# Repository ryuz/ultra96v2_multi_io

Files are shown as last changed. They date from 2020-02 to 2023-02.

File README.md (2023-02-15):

# Ultra96V2用マルチI/O拡張カード

現在デバッグ中ですが、MIPI-CSI の動作確認できました。

## 開発イメージ

下記のようなイメージで開発している [Ultra96V2](https://www.avnet.com/wps/portal/japan/products/product-highlights/ultra96/) 向けのI/O拡張ボードです。

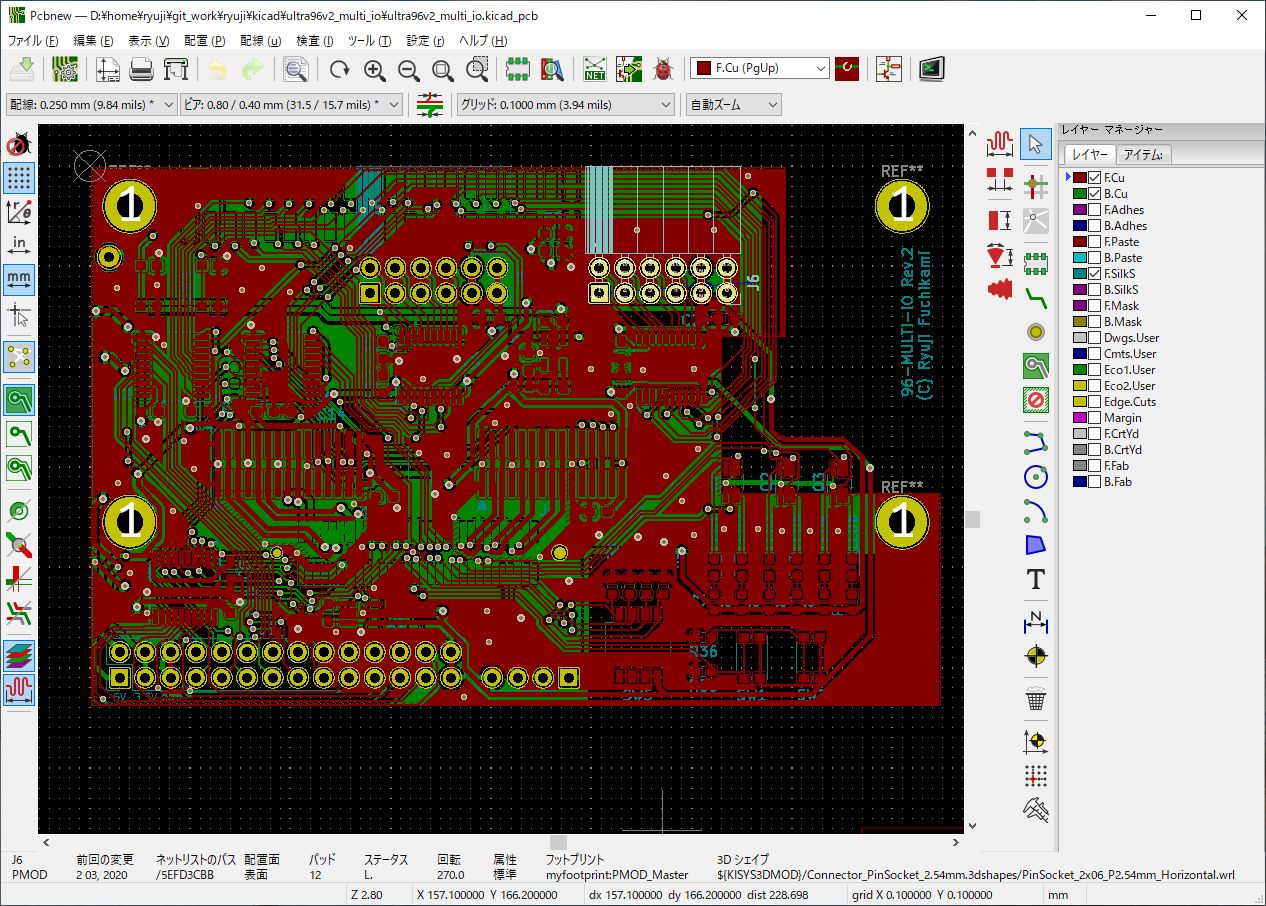
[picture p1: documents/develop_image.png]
開発イメージ
 

## 設計コンセプト

コンセプトは

- [FusionPCB](https://www.fusionpcb.jp)さんの$4.9基板で作る
- [ZYBO](https://reference.digilentinc.com/reference/programmable-logic/zybo-z7/start) の良さ(PLのI/O機能の充実)の追加
- [Raspberry PI](https://ja.wikipedia.org/wiki/Raspberry_Pi) の良さ(PSのI/O機能の充実)の追加
- 使いたい機能だけ部品実装すれば最低限のコストで使える

です。

## 機能

主な機能として

- PLの機能
    - TXS0108で3.3V双方向変換した12pin PMOD × 2個
    - RaspberryPI互換 MIPI-CSIコネクタ× 2個
    - LED × 4個
    - プッシュスイッチ × 2個 
    - ディップスイッチ(4bit) × 1個 
    - 25MHzクロック供給
- PSの機能
    - LED × 2個
    - TXS0108で3.3V双方向変換したGPIO
    - TXS0108で3.3V双方向変換したI2C
    - TXS0108で3.3V双方向変換したSPI
- その他の機能
    - 隠れると困るPWR/RSTスイッチの引き出し
    - 申し訳程度にUSB2.0信号を引き出したピンヘッダ

特に MIPI-CSI は、[こちら](http://nahitafu.cocolog-nifty.com/nahitafu/2008/11/post-57a1.html)を参考にさせて頂いて、基板厚 0.6mm の想定で設計時の机上計算のみ行っています)。

## 回路図

回路図は[こちら](documents/ultra96v2_multi_io_schematic.pdf)

## 追加情報

こちらに[ブログ記事](https://ryuz.hatenablog.com/entry/2020/07/26/215500)を書きました。

## 修正履歴

- Rev.1 2020/02/11
   - 修正内容
       - 初版
   - 動作状況
       - MIPI-CSI が同パターンの別基板でデータ受信でき無かったため、部品温存で試さずに Rev.2 製造へ

- Rev.2 2020/03/08
   - 修正内容
       - MIPI 配線レイアウト変更
       - 基板厚を 0.6mm に変更して発注
   - 動作状況
       - J3のMIPI-CSI動作確認(I2Cプルアップをリワーク修正)
       - J4のMIPI-CSI動作確認(I2Cプルアップをリワーク修正)
       - PMODの出力パルス波形確認
       - SW5(DIP-SW)の型番とフットプリントが不一致で実装できず
       - MIPI-DSIの端子をLVCMOS利用箇所でLVCMOS18と勘違いしておりLED点灯が暗い(実際はLVCMOS12)
       - 他はこれから試す予定

- Rev.3 2023/02/15
   - MIPI-CSI用 I2C プルアップ抵抗抜け修正(R23～26追加)
   - LS_GPIO_2 と LS_GPIO_6 の U4 への接続をスワップ
   - Q1-4 の DMN63D8LDW-7 -> DMN5L0-6DWK7 に変更(LVCMOS12対応)
   - SW5 の GDH04S04 のフットプリントが A6H-4101 用になっていたので両対応パターンに変更
   - fumi氏に HSコネクタに来ている信号のうち Bank65 に繋がるものがは 1.2V だと指摘頂き下記を修正
       - SW1, SW2, SW5 を FPGA内部PULLUPして論理逆で使う方針に変更(R35, R36, R31, R32, R33, R34 削除)
       - U3 を使わずにそのままピンヘッダへ (U3, C8, C10, R11, R12 削除)
       - KiCAD を 7.0.0 へ更新

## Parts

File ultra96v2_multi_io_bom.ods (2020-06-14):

Reference | Quantity | Value |  |  |  | digikey |  | Footprint | Datasheet
C1 C2 C6 | 3 | 10uF | 22 | 66 | GRM188R60J106KE47D | 490-12538-1-ND | https://www.digikey.jp/product-detail/ja/murata-electronics/GRM188R60J106KE47D/490-12538-1-ND/5797528 | Capacitor_SMD:C_0603_1608Metric_Pad1.05x0.95mm_HandSolder | ~
C12 C11 C13 C15 C18 C19 C14 C16 C7 C4 C5 C8 C10 | 13 | 0.1uF | 12 | 156 | C0603C104Z3VACTU | 399-1100-1-ND | https://www.digikey.jp/product-detail/ja/kemet/C0603C104Z3VACTU/399-1100-1-ND/411375 | Capacitor_SMD:C_0603_1608Metric_Pad1.05x0.95mm_HandSolder | ~
C3 C17 C20 | 3 | 4.7uF | 20 | 60 | CC0603ZRY5V5BB475 | 311-1453-1-ND | https://www.digikey.jp/product-detail/ja/yageo/CC0603ZRY5V5BB475/311-1453-1-ND/2833759 | Capacitor_SMD:C_0603_1608Metric_Pad1.05x0.95mm_HandSolder | ~
C9 | 1 | <0.1uF> |  | 0 |  |  |  | Capacitor_SMD:C_0603_1608Metric_Pad1.05x0.95mm_HandSolder | ~
J1 | 1 | TE 5179030-2 | 690 | 690 | 61083-063402LF | 609-1679-1-ND | https://www.digikey.jp/product-detail/ja/amphenol-icc-fci/61083-063402LF/609-1679-1-ND/1002898 | myfootprint:61083-063402LF | ~
J2 | 1 | 57202-G52-20LF | 576 | 576 | 57202-G52-20LF | 609-2632-ND | https://www.digikey.jp/products/ja?keywords=57202-G52-20LF | myfootprint:PinHeader_2x20_P2.00mm_Vertical_SMD_REV | ~
J4 J3 | 2 | 1-1734248-5 | 123 | 246 | 1-1734248-5 | A101418CT-ND | https://www.digikey.jp/product-detail/ja/te-connectivity-amp-connectors/1-1734248-5/A101418CT-ND/2567554 | myfootprint:55510-140LF | ~
J5 J6 | 2 | PMOD | 138 | 276 | SSW-106-02-T-D-RA | SAM10026-ND | https://www.digikey.jp/product-detail/ja/samtec-inc/SSW-106-02-T-D-RA/SAM10026-ND/6678763 | myfootprint:PMOD_Master | ~
J7 | 1 | PinHeader |  | 0 |  |  |  | Connector_PinHeader_2.54mm:PinHeader_2x14_P2.54mm_Vertical | ~
J8 | 1 | Conn_01x04 |  | 0 |  |  |  | Connector_PinHeader_2.54mm:PinHeader_1x04_P2.54mm_Vertical | ~
L2 | 1 | 2.2uH 2012 | 34 | 34 | LQM21PN2R2MC0D | 490-4994-1-ND | https://www.digikey.jp/product-detail/ja/murata-electronics/LQM21PN2R2MC0D/490-4994-1-ND/1788292 | Inductor_SMD:L_0805_2012Metric | ~
LED1 LED2 LED3 LED4 LED5 LED6 | 6 | SML-512MWT86 | 53 | 318 | SML-512MWT86 | 511-1313-1-ND | https://www.digikey.jp/product-detail/ja/rohm-semiconductor/SML-512MWT86/511-1313-1-ND/637126 | LED_SMD:LED_0603_1608Metric_Pad1.05x0.95mm_HandSolder | https://www.prtice.info/IMG/pdf/CQY99.pdf
Q1 Q2 Q3 | 3 | DMN63D8LDW-7 | 36 | 108 |  | DMN63D8LDW-7CT-ND | https://www.digikey.jp/product-detail/ja/diodes-incorporated/DMN63D8LDW-7/DMN63D8LDW-7CT-ND/3829373 | Package_TO_SOT_SMD:SOT-363_SC-70-6_Handsoldering | http://www.irf.com/product-info/datasheets/data/irf7309ipbf.pdf
R15 R16 R17 R18 R14 R20 R7 R8 R2 R12 | 10 | <0> |  | 0 |  |  |  | Resistor_SMD:R_0603_1608Metric | ~
R3 R4 R5 R6 R9 R10 | 6 | 200 | 12 | 72 | RC0603FR-07200RL | 311-200HRCT-ND | https://www.digikey.jp/product-detail/ja/yageo/RC0603FR-07200RL/311-200HRCT-ND/729990 | Resistor_SMD:R_0603_1608Metric | ~
R30 R13 R19 R1 R11 R21 R22 | 7 | 0 | 12 | 84 | RC0603JR-070RL | 311-0.0GRCT-ND | https://www.digikey.jp/product-detail/ja/yageo/RC0603JR-070RL/311-0.0GRCT-ND/729622 | Resistor_SMD:R_0603_1608Metric | ~
R36 R35 R34 R33 R32 R31 | 6 | 4.7k | 12 | 72 | RC0603JR-074K7L | 311-4.7KGRCT-ND | https://www.digikey.jp/product-detail/ja/yageo/RC0603JR-074K7L/311-4.7KGRCT-ND/729732 | Resistor_SMD:R_0603_1608Metric | ~
SW1 SW2 SW3 SW4 | 4 | KMR213G LFG | 77 | 308 | KMR223GLFG | 401-1428-1-ND | https://www.digikey.jp/product-detail/ja/c-k/KMR223GLFG/401-1428-1-ND/550463 | Button_Switch_SMD:SW_Push_1P1T_NO_CK_KMR2 | ~
SW5 | 1 | GDH04S04 | 210 | 210 | GDH04S04 | 450-1353-ND | https://www.digikey.jp/products/ja?keywords=GDH04S04 | Button_Switch_SMD:SW_DIP_SPSTx04_Slide_Omron_A6H-4101_W6.15mm_P1.27mm | ~
TP1 | 1 | TP_GND |  | 0 |  |  |  | TestPoint:TestPoint_Loop_D1.80mm_Drill1.0mm_Beaded | ~
U1 | 1 | LM3671MF-3.3 | 166 | 166 |  | LM3671MF-3.3/NOPBCT-ND | https://www.digikey.jp/product-detail/ja/texas-instruments/LM3671MF-3.3-NOPB/LM3671MF-3.3-NOPBCT-ND/1590190 | Package_TO_SOT_SMD:TSOT-23-5 | http://www.ti.com/lit/ds/symlink/lm3670.pdf
U4 U6 U5 U2 U3 | 5 | TXS0108EPW | 193 | 965 |  | 296-23011-1-ND | https://www.digikey.jp/product-detail/ja/texas-instruments/TXS0108EPWR/296-23011-1-ND/1775304 | Package_SO:TSSOP-20_4.4x6.5mm_P0.65mm | www.ti.com/lit/ds/symlink/txs0108e.pdf
X1 | 1 | SIT2024BA-S3-18E-25.000000G | 251 | 251 |  | 1473-SIT2018AE-S3-18N-20.000000E-ND | https://www.digikey.jp/product-detail/ja/sitime/SIT2024BA-S3-18E-25.000000G/1473-1594-1-ND/6677389 | Package_TO_SOT_SMD:SOT-23-5_HandSoldering
X2 | 1 | <xxxMHz> |  | 0 |  |  |  | Oscillator:Oscillator_SMD_Abracon_ASDMB-4Pin_2.5x2.0mm | https://abracon.com/Oscillators/ASDMB.pdf
 |  |  |  | 4658

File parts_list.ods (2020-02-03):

 |  |  |  | 個数 |  | RS-ONLINE | digikey | 備考
LSコネクタ |  | 57202-G52-10LF |  | 5 | 288 | https://jp.rs-online.com/web/p/pcb-headers/6737604/ | https://www.digikey.jp/product-detail/ja/amphenol-icc-fci/57202-G52-20LF/609-2632-ND/1090245 | 57202-G52-20LFが手に入る場合は1個
HSコネクタ | TE | TE 5179030-2 |  | 1 | 498 | https://jp.rs-online.com/web/p/pcb-headers/3616620/ |  | 61083-063402LF でもよい
保護ダイオード？
双方向レベル変換 |  | TXB0108PWR |  | 2 | 168 | https://jp.rs-online.com/web/p/voltage-translators/7099038/ | https://www.digikey.jp/product-detail/ja/texas-instruments/TXB0108PWR/296-21527-1-ND/1305700
抵抗内蔵トランジスタ | Rhom | DTC114EKAT146 | TO-236-3、SC-59、SOT-23-3 | 8 |  | https://jp.rs-online.com/web/p/digital-transistors/2461693/ | https://www.digikey.jp/product-detail/ja/rohm-semiconductor/DTC114EKAT146/DTC114EKAT146CT-ND/650710
LED |  | SML-512MWT86 |  | 8 |  | https://jp.rs-online.com/web/p/leds/7007972/
 |  | SSM3K15F
 | OSC | SIT2024BA-S3-18E-25.000000G

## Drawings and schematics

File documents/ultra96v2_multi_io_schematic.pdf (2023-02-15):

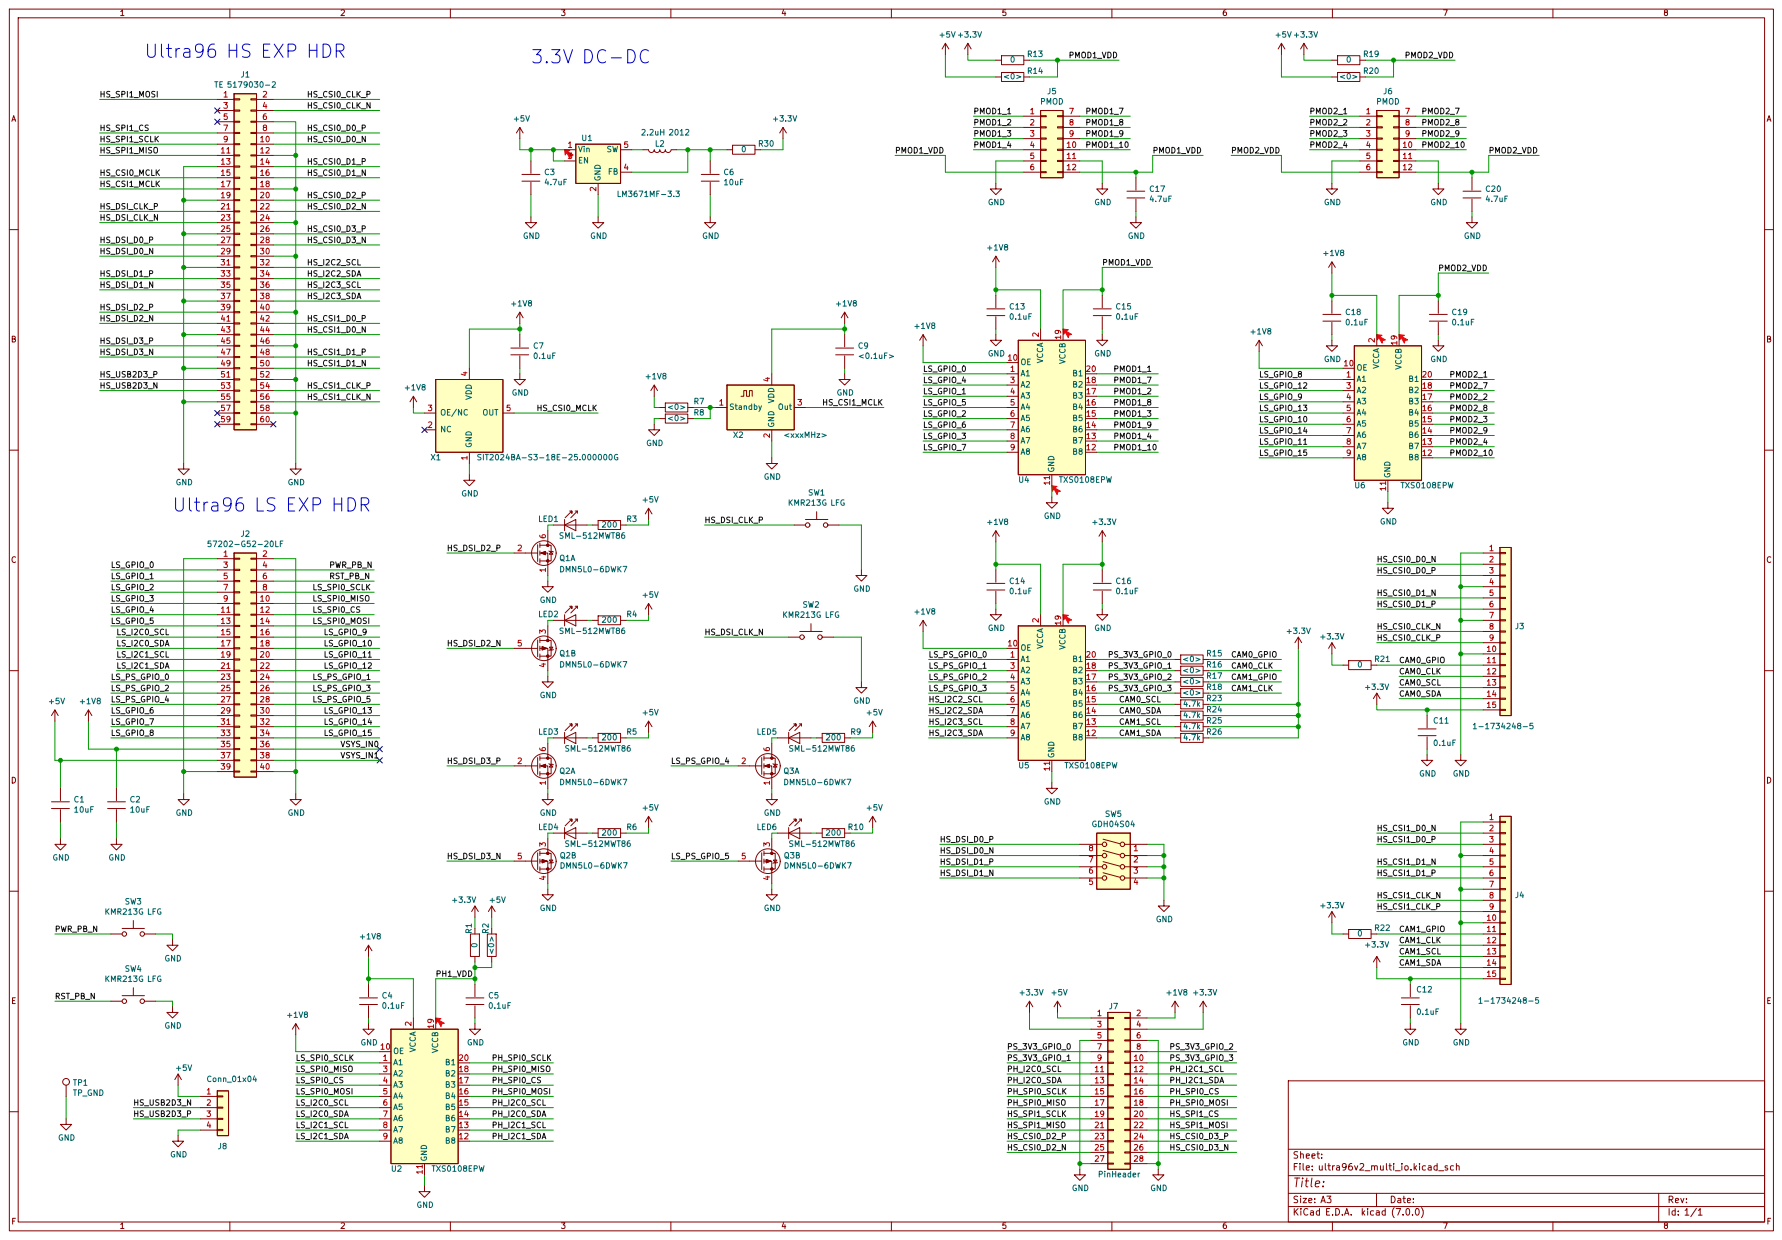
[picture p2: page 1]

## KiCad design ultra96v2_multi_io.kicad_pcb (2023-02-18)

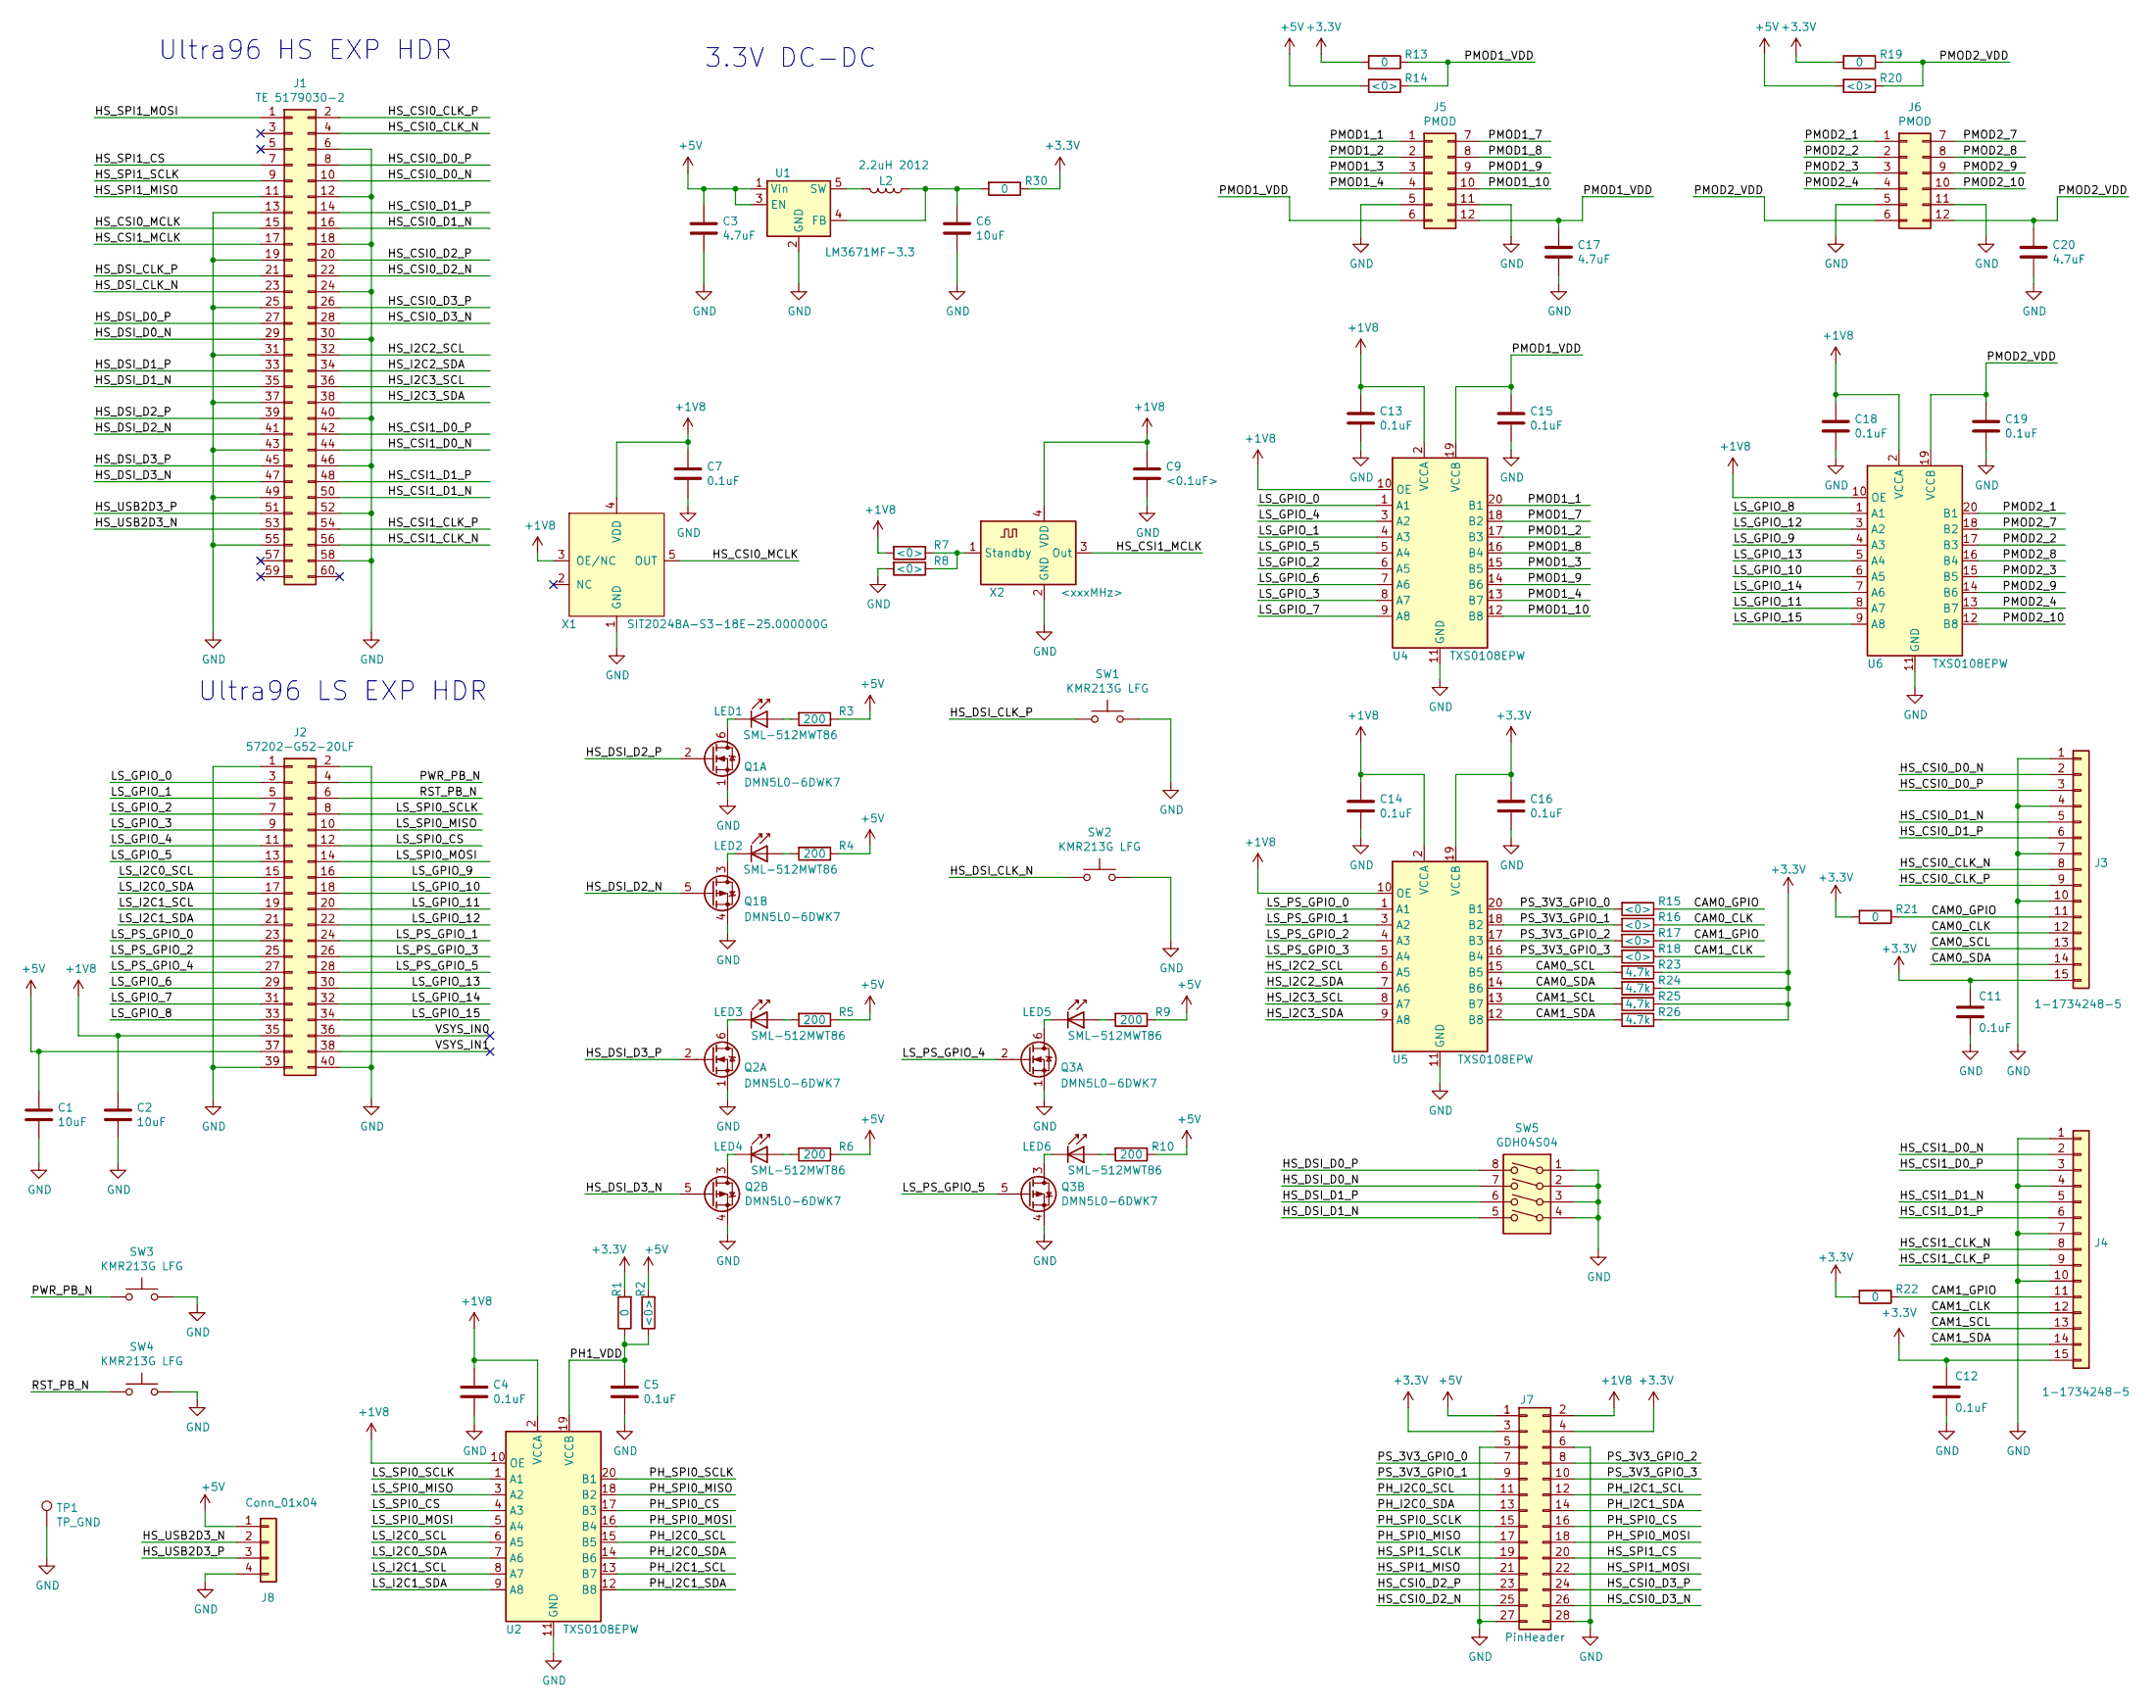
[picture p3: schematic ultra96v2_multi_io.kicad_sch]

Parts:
C1, C2, C6: 10uF; C_0603_1608Metric_Pad1.05x0.95mm_HandSolder
C3, C17, C20: 4.7uF; C_0603_1608Metric_Pad1.05x0.95mm_HandSolder
C4, C5, C7, C11, C12, C13, C14, C15, C16, C18, C19: 0.1uF; C_0603_1608Metric_Pad1.05x0.95mm_HandSolder
C9: <0.1uF>; C_0603_1608Metric_Pad1.05x0.95mm_HandSolder
J1: TE 5179030-2; 61083-063402LF
J2: 57202-G52-20LF; PinHeader_2x20_P2.00mm_Vertical_SMD_REV
J3, J4: 1-1734248-5; 55510-140LF_handsolder
J5, J6: PMOD; PMOD_Master
J7: PinHeader; PinHeader_2x14_P2.54mm_Vertical
J8: Conn_01x04; PinHeader_1x04_P2.54mm_Vertical
L2: 2.2uH 2012; L_0805_2012Metric
LED1, LED2, LED3, LED4, LED5, LED6: SML-512MWT86; LED_0603_1608Metric_Pad1.05x0.95mm_HandSolder
Q1, Q2, Q3: DMN5L0-6DWK7; SOT-363_SC-70-6_Handsoldering
R1, R13, R19, R21, R22, R30: 0; R_0603_1608Metric
R2, R7, R8, R14, R15, R16, R17, R18, R20: <0>; R_0603_1608Metric
R3, R4, R5, R6, R9, R10: 200; R_0603_1608Metric
R23, R24, R25, R26: 4.7k; R_0603_1608Metric
SW1, SW2, SW3, SW4: KMR213G LFG; SW_Push_1P1T_NO_CK_KMR2
SW5: GDH04S04; SW_DIP_multi_io
TP1: TP_GND; TestPoint_Loop_D1.80mm_Drill1.0mm_Beaded
U1: LM3671MF-3.3; TSOT-23-5
U2, U4, U5, U6: TXS0108EPW; TSSOP-20_4.4x6.5mm_P0.65mm
X1: SIT2024BA-S3-18E-25.000000G; SOT-23-5_HandSoldering
X2: <xxxMHz>; Oscillator_SMD_Abracon_ASDMB-4Pin_2.5x2.0mm

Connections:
+1V8: C2.1, C4.1, C7.1, C9.1, C13.1, C14.1, C18.1, J2.35, J7.2, R7.2, U2.2 (VCCA), U2.10 (OE), U4.2 (VCCA), U4.10 (OE), U5.2 (VCCA), U5.10 (OE), U6.2 (VCCA), U6.10 (OE), X1.3 (OE/NC), X1.4 (VDD), X2.4 (VDD)
+3V3: C11.1, C12.1, C16.1, J3.15, J4.15, J7.3, J7.4, R1.2, R13.2, R19.2, R21.2, R22.2, R23.1, R24.1, R25.1, R26.1, R30.1, U5.19 (VCCB)
+5V: C1.1, C3.1, J2.37, J7.1, J8.1, R2.2, R3.1, R4.1, R5.1, R6.1, R9.1, R10.1, R14.2, R20.2, U1.1 (Vin), U1.3 (EN)
/CAM0_CLK: J3.12, R16.1
/CAM0_GPIO: J3.11, R15.1, R21.1
/CAM0_SCL: J3.13, R23.2, U5.15 (B5)
/CAM0_SDA: J3.14, R24.2, U5.14 (B6)
/CAM1_CLK: J4.12, R18.1
/CAM1_GPIO: J4.11, R17.1, R22.1
/CAM1_SCL: J4.13, R25.2, U5.13 (B7)
/CAM1_SDA: J4.14, R26.2, U5.12 (B8)
/HS_CSI0_CLK_N: J1.4, J3.8
/HS_CSI0_CLK_P: J1.2, J3.9
/HS_CSI0_D0_N: J1.10, J3.2
/HS_CSI0_D0_P: J1.8, J3.3
/HS_CSI0_D1_N: J1.16, J3.5
/HS_CSI0_D1_P: J1.14, J3.6
/HS_CSI0_D2_N: J1.22, J7.25
/HS_CSI0_D2_P: J1.20, J7.23
/HS_CSI0_D3_N: J1.28, J7.26
/HS_CSI0_D3_P: J1.26, J7.24
/HS_CSI0_MCLK: J1.15, X1.5 (OUT)
/HS_CSI1_CLK_N: J1.56, J4.8
/HS_CSI1_CLK_P: J1.54, J4.9
/HS_CSI1_D0_N: J1.44, J4.2
/HS_CSI1_D0_P: J1.42, J4.3
/HS_CSI1_D1_N: J1.50, J4.5
/HS_CSI1_D1_P: J1.48, J4.6
/HS_CSI1_MCLK: J1.17, X2.3 (Out)
/HS_DSI_CLK_N: J1.23, SW2.1
/HS_DSI_CLK_P: J1.21, SW1.1
/HS_DSI_D0_N: J1.29, SW5.7
/HS_DSI_D0_P: J1.27, SW5.8
/HS_DSI_D1_N: J1.35, SW5.5
/HS_DSI_D1_P: J1.33, SW5.6
/HS_DSI_D2_N: J1.41, Q1.5 (G2)
/HS_DSI_D2_P: J1.39, Q1.2 (G1)
/HS_DSI_D3_N: J1.47, Q2.5 (G2)
/HS_DSI_D3_P: J1.45, Q2.2 (G1)
/HS_I2C2_SCL: J1.32, U5.6 (A5)
/HS_I2C2_SDA: J1.34, U5.7 (A6)
/HS_I2C3_SCL: J1.36, U5.8 (A7)
/HS_I2C3_SDA: J1.38, U5.9 (A8)
/HS_SPI1_CS: J1.7, J7.20
/HS_SPI1_MISO: J1.11, J7.21
/HS_SPI1_MOSI: J1.1, J7.22
/HS_SPI1_SCLK: J1.9, J7.19
/HS_USB2D3_N: J1.53, J8.2
/HS_USB2D3_P: J1.51, J8.3
/LS_GPIO_0: J2.3, U4.1 (A1)
/LS_GPIO_1: J2.5, U4.4 (A3)
/LS_GPIO_2: J2.7, U4.6 (A5)
/LS_GPIO_3: J2.9, U4.8 (A7)
/LS_GPIO_4: J2.11, U4.3 (A2)
/LS_GPIO_5: J2.13, U4.5 (A4)
/LS_GPIO_6: J2.29, U4.7 (A6)
/LS_GPIO_7: J2.31, U4.9 (A8)
/LS_GPIO_8: J2.33, U6.1 (A1)
/LS_GPIO_9: J2.16, U6.4 (A3)
/LS_GPIO_10: J2.18, U6.6 (A5)
/LS_GPIO_11: J2.20, U6.8 (A7)
/LS_GPIO_12: J2.22, U6.3 (A2)
/LS_GPIO_13: J2.30, U6.5 (A4)
/LS_GPIO_14: J2.32, U6.7 (A6)
/LS_GPIO_15: J2.34, U6.9 (A8)
/LS_I2C0_SCL: J2.15, U2.6 (A5)
/LS_I2C0_SDA: J2.17, U2.7 (A6)
/LS_I2C1_SCL: J2.19, U2.8 (A7)
/LS_I2C1_SDA: J2.21, U2.9 (A8)
/LS_PS_GPIO_0: J2.23, U5.1 (A1)
/LS_PS_GPIO_1: J2.24, U5.3 (A2)
/LS_PS_GPIO_2: J2.25, U5.4 (A3)
/LS_PS_GPIO_3: J2.26, U5.5 (A4)
/LS_PS_GPIO_4: J2.27, Q3.2 (G1)
/LS_PS_GPIO_5: J2.28, Q3.5 (G2)
/LS_SPI0_CS: J2.12, U2.4 (A3)
/LS_SPI0_MISO: J2.10, U2.3 (A2)
/LS_SPI0_MOSI: J2.14, U2.5 (A4)
/LS_SPI0_SCLK: J2.8, U2.1 (A1)
/PH1_VDD: C5.1, R1.1, R2.1, U2.19 (VCCB)
/PH_I2C0_SCL: J7.11, U2.15 (B5)
/PH_I2C0_SDA: J7.13, U2.14 (B6)
/PH_I2C1_SCL: J7.12, U2.13 (B7)
/PH_I2C1_SDA: J7.14, U2.12 (B8)
/PH_SPI0_CS: J7.16, U2.17 (B3)
/PH_SPI0_MISO: J7.17, U2.18 (B2)
/PH_SPI0_MOSI: J7.18, U2.16 (B4)
/PH_SPI0_SCLK: J7.15, U2.20 (B1)
/PMOD1_1: J5.1, U4.20 (B1)
/PMOD1_2: J5.2, U4.17 (B3)
/PMOD1_3: J5.3, U4.15 (B5)
/PMOD1_4: J5.4, U4.13 (B7)
/PMOD1_7: J5.7, U4.18 (B2)
/PMOD1_8: J5.8, U4.16 (B4)
/PMOD1_9: J5.9, U4.14 (B6)
/PMOD1_10: J5.10, U4.12 (B8)
/PMOD1_VDD: C15.1, C17.1, J5.6, J5.12, R13.1, R14.1, U4.19 (VCCB)
/PMOD2_1: J6.1, U6.20 (B1)
/PMOD2_2: J6.2, U6.17 (B3)
/PMOD2_3: J6.3, U6.15 (B5)
/PMOD2_4: J6.4, U6.13 (B7)
/PMOD2_7: J6.7, U6.18 (B2)
/PMOD2_8: J6.8, U6.16 (B4)
/PMOD2_9: J6.9, U6.14 (B6)
/PMOD2_10: J6.10, U6.12 (B8)
/PMOD2_VDD: C19.1, C20.1, J6.6, J6.12, R19.1, R20.1, U6.19 (VCCB)
/PS_3V3_GPIO_0: J7.7, R15.2, U5.20 (B1)
/PS_3V3_GPIO_1: J7.9, R16.2, U5.18 (B2)
/PS_3V3_GPIO_2: J7.8, R17.2, U5.17 (B3)
/PS_3V3_GPIO_3: J7.10, R18.2, U5.16 (B4)
/PWR_PB_N: J2.4, SW3.1
/RST_PB_N: J2.6, SW4.1
/VSYS_IN0: J2.36
/VSYS_IN1: J2.38
GND: C1.2, C2.2, C3.2, C4.2, C5.2, C6.2, C7.2, C9.2, C11.2, C12.2, C13.2, C14.2, C15.2, C16.2, C17.2, C18.2, C19.2, C20.2, J1.6, J1.12, J1.13, J1.18, J1.19, J1.24, J1.25, J1.30, J1.31, J1.37, J1.40, J1.43, J1.46, J1.49, J1.52, J1.55, J1.58, J2.1, J2.2, J2.39, J2.40, J3.1, J3.4, J3.7, J3.10, J4.1, J4.4, J4.7, J4.10, J5.5, J5.11, J6.5, J6.11, J7.5, J7.6, J7.27, J7.28, J8.4, Q1.1 (S1), Q1.4 (S2), Q2.1 (S1), Q2.4 (S2), Q3.1 (S1), Q3.4 (S2), R8.2, SW1.2, SW2.2, SW3.2, SW4.2, SW5.1, SW5.2, SW5.3, SW5.4, TP1.1, U1.2 (GND), U2.11 (GND), U4.11 (GND), U5.11 (GND), U6.11 (GND), X1.1 (GND), X2.2 (GND)
unnamed: LED1.2 (A), R3.2
unnamed: LED1.1 (K), Q1.6 (D1)
unnamed: LED2.2 (A), R4.2
unnamed: LED2.1 (K), Q1.3 (D2)
unnamed: LED3.2 (A), R5.2
unnamed: LED3.1 (K), Q2.6 (D1)
unnamed: LED4.2 (A), R6.2
unnamed: LED4.1 (K), Q2.3 (D2)
unnamed: LED5.2 (A), R9.2
unnamed: LED5.1 (K), Q3.6 (D1)
unnamed: LED6.2 (A), R10.2
unnamed: LED6.1 (K), Q3.3 (D2)
unnamed: C6.1, L2.1, R30.2, U1.4 (FB)
unnamed: L2.2, U1.5 (SW)
unnamed: R7.1, R8.1, X2.1 (Standby)

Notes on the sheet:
Ultra96 LS EXP HDR
3.3V DC-DC
Ultra96 HS EXP HDR

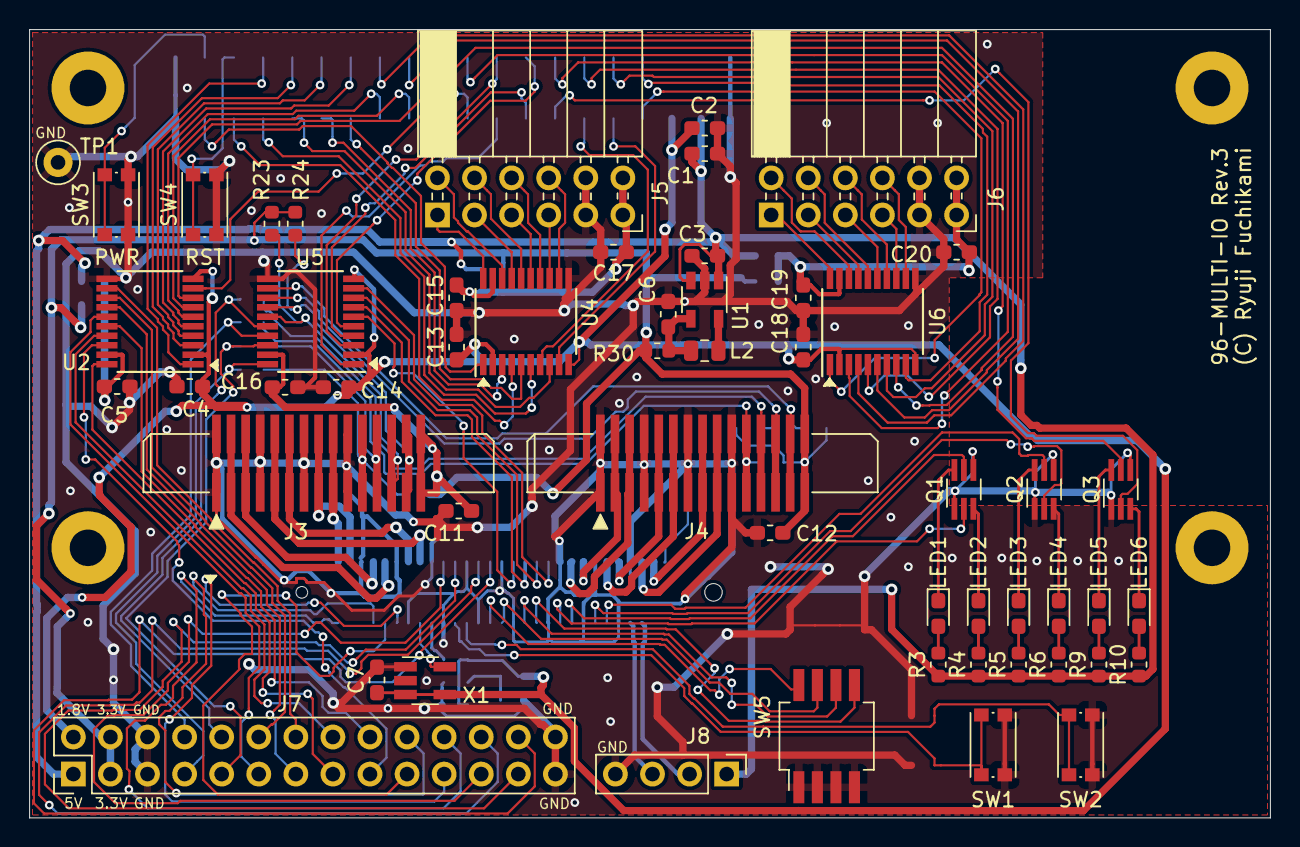
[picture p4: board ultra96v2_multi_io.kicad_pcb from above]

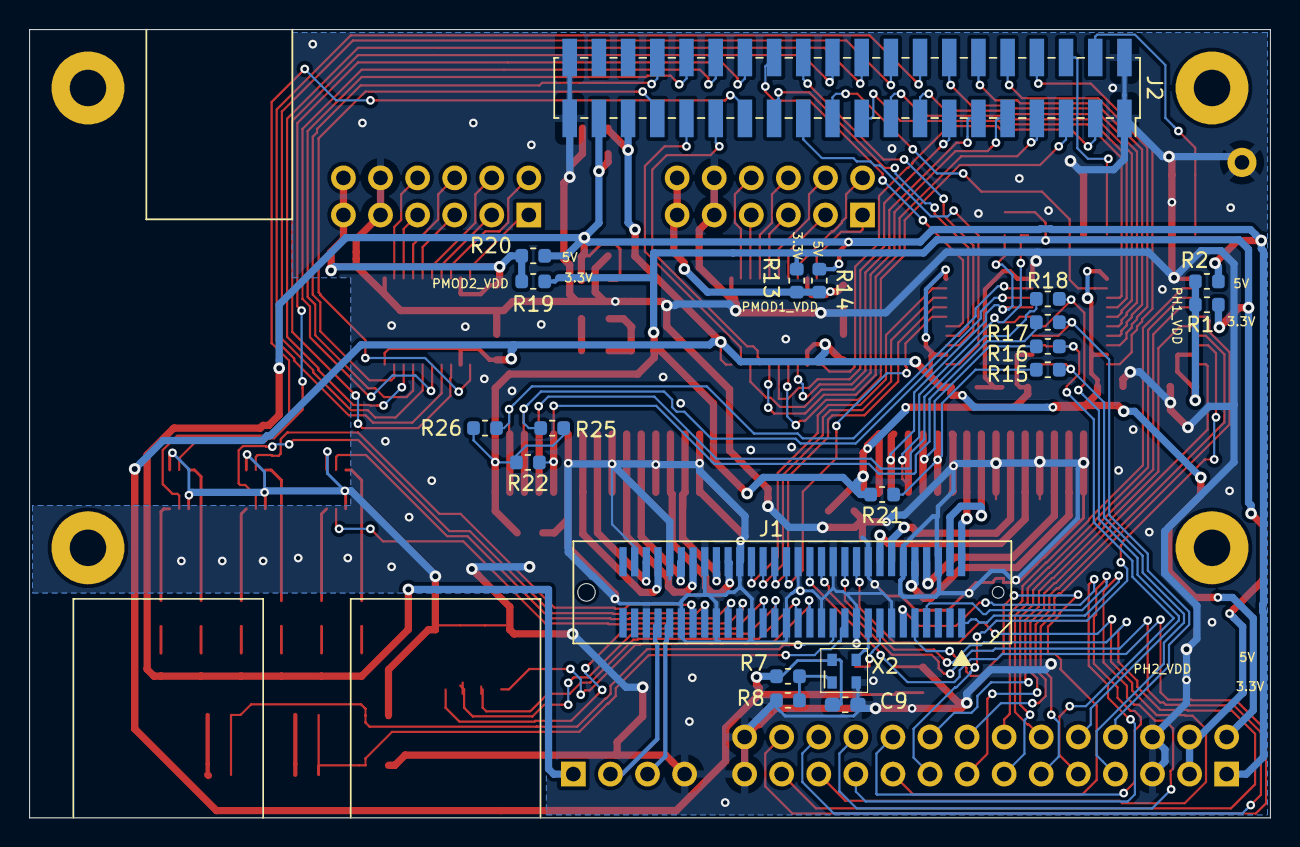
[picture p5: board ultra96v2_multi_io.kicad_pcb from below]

Board: 2 copper layers, 85.0 x 54.0 mm, 74 parts (20 on the bottom side), 128 nets.

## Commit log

2020-03-08 update rev2
    [ultra96v2_multi_io.kicad_pcb]
2020-06-14 update document
    [ultra96v2_multi_io_bom.ods]
2020-07-21 update to rev3 add MIPI-SCI I2C pullup register
    [ultra96v2_multi_io.kicad_pcb, ultra96v2_multi_io.sch]
2020-07-25 LS_GPIO_2 と LS_GPIO_6 の U4 への接続をスワップ
    [ultra96v2_multi_io.kicad_pcb, ultra96v2_multi_io.sch]
2020-07-26 Q1-4 の DMN63D8LDW-7 -> DMN5L0-6DWK7 に変更(LVCMOS12対応) SW5 の GDH04S04 のフットプリントが A6H-4101 用になっていたので両対応パターンに変更
    [ultra96v2_multi_io.kicad_pcb, ultra96v2_multi_io.sch]
2020-07-26 add SW_DIP_multi_io.kicad_mod
2023-02-15 HSコネクタの 1.2V信号を誤って 1.8V として扱っていた点を修正。
    詳細はREADME参照の事
    [ultra96v2_multi_io.kicad_pcb, ultra96v2_multi_io.kicad_sch]
2023-02-18 未接続ネットの削除など
    [ultra96v2_multi_io.kicad_pcb]
